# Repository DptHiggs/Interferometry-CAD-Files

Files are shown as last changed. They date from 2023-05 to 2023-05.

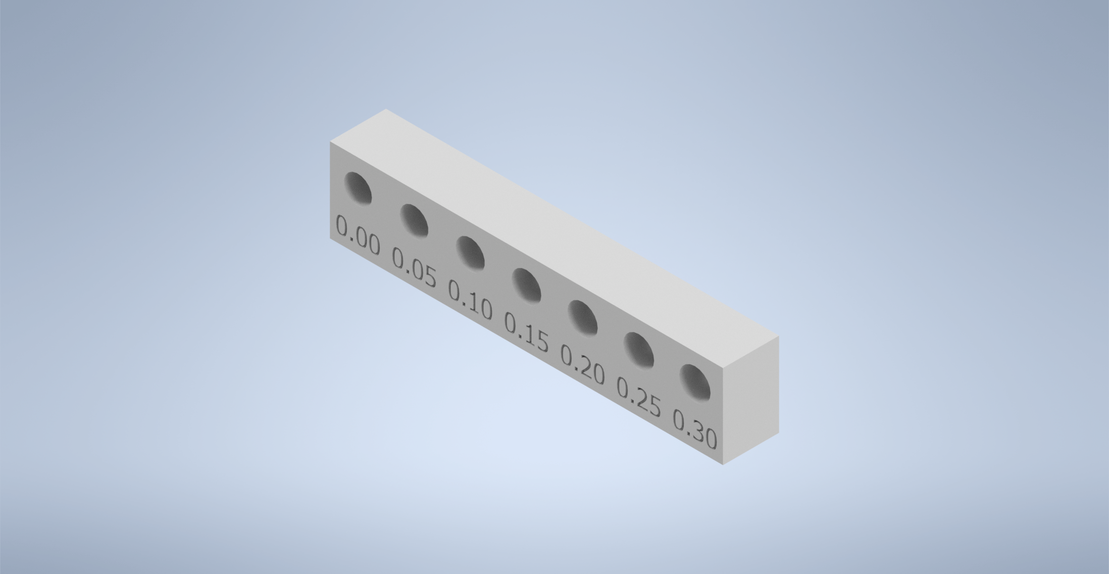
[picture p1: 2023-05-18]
RENDERS/FIT TEST.png

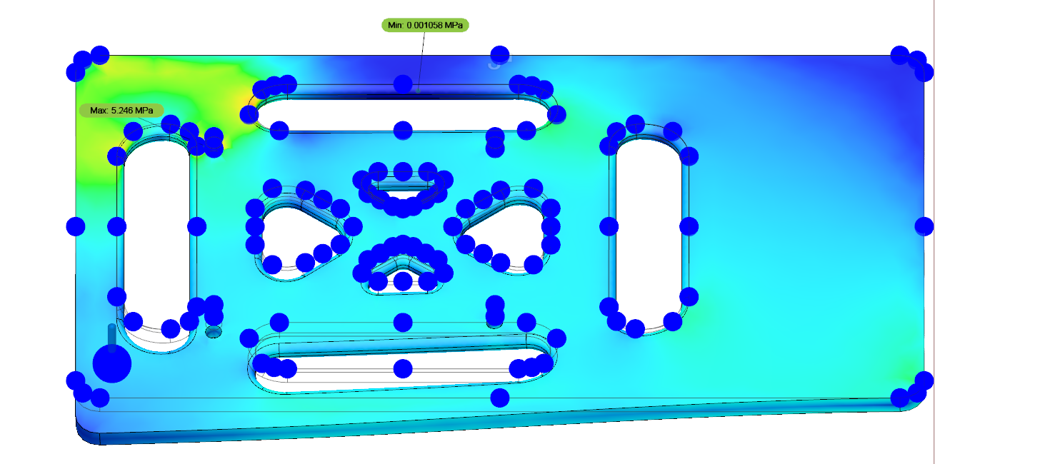
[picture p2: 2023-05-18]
SIMULATIONS/FEA/COMPONENT SHELF/COMPONENT SHELF 2/Screenshot 2023-05-17 142134.png

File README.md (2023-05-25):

# Interferometry-CAD-Files
Repository containing all CAD files and simulation reports for GDBP Lightning Interferometry enclosure design

All CAD files are stored in CAD folder <br>
LI designation denotes parts designed for this project <br>
LIA designation denotes assemblies designed for this project.

SIMULATIONS contains all simulation results and reports

RENDERS contains images of design

Links to other CAD files used <br>
https://grabcad.com/library/arduino-uno-r3-1 <br>
https://grabcad.com/library/raspberry-pi-4-model-b-1 <br>
https://uk.farnell.com/pulse-electronics/w9011m/cable-assy-u-fl-r-a-plug-sma-jack/dp/3861118 <br>
https://uk.rs-online.com/web/p/ethernet-couplers/1116746 <br>
https://uk.rs-online.com/web/p/usb-cables/1116748 <br>
https://uk.rs-online.com/web/p/fan-filters/7134396 <br>
https://www.accu.co.uk/threaded-hexagonal-spacers/464774-HHTPS-M3-5-5-8-SS?google_shopping=1&c=5 <br>
https://www.te.com/usa-en/product-1-1609112-4.html <br>
https://grabcad.com/library/arduino-due-1 <br>

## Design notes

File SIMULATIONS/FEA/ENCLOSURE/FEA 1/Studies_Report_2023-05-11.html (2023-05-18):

Image Width (pixels):

# Study Report

Analyzed File | LIA0003-CASE ASSY v2
Version | Autodesk Fusion 360 (2.0.16009)
Creation Date | 2023-05-11, 11:05:16
Author | rudy

#### Report Properties

Title | Studies
Author | rudy

## Simulation Model 1:1

### Study 1 - Static Stress

##### Study Properties

Study Type | Static Stress
Last Modification Date | 2023-05-11, 10:39:01

#### Settings

##### General

Contact Tolerance | 0.1 mm
Remove Rigid Body Modes | No

##### Damping

##### Mesh

Average Element Size (% of model size)
Solids | 10
Scale Mesh Size Per Part | No
Average Element Size (absolute value) | -
Element Order | Parabolic
Create Curved Mesh Elements | Yes
Max. Turn Angle on Curves (Deg.) | 60
Max. Adjacent Mesh Size Ratio | 1.5
Max. Aspect Ratio | 10
Minimum Element Size (% of average size) | 20

##### Adaptive Mesh Refinement

Number of Refinement Steps | 0
Results Convergence Tolerance (%) | 20
Portion of Elements to Refine (%) | 10
Results for Baseline Accuracy | Von Mises Stress

#### Materials

Component | Material | Safety Factor
LI0001-CASE BODY:1 | ABS Plastic | Yield Strength
LI0013-FOOT:1/Simplified Primitive:1 | Steel | Yield Strength
LI0013-FOOT:2/Simplified Primitive:1 | Steel | Yield Strength
LI0013-FOOT:3/Simplified Primitive:1 | Steel | Yield Strength
LI0013-FOOT:4/Simplified Primitive:1 | Steel | Yield Strength

##### Steel

Density | 7.85E-06 kg / mm^3
Young's Modulus | 210000 MPa
Poisson's Ratio | 0.3
Yield Strength | 207 MPa
Ultimate Tensile Strength | 345 MPa
Thermal Conductivity | 0.056 W / (mm C)
Thermal Expansion Coefficient | 1.2E-05 / C
Specific Heat | 480 J / (kg C)

##### ABS Plastic

Density | 1.06E-06 kg / mm^3
Young's Modulus | 2240 MPa
Poisson's Ratio | 0.38
Yield Strength | 20 MPa
Ultimate Tensile Strength | 29.6 MPa
Thermal Conductivity | 1.6E-04 W / (mm C)
Thermal Expansion Coefficient | 8.57E-05 / C
Specific Heat | 1500 J / (kg C)

#### Contacts

##### Bonded

Name

[S] Bonded56 [LI0001-CASE BODY:1||Simplified Primitive:1]

[S] Bonded57 [LI0001-CASE BODY:1||Simplified Primitive:1]

[S] Bonded58 [LI0001-CASE BODY:1||Simplified Primitive:1]

[S] Bonded59 [LI0001-CASE BODY:1||Simplified Primitive:1]

[S] Bonded60 [LI0001-CASE BODY:1||Simplified Primitive:1]

[S] Bonded61 [LI0001-CASE BODY:1||Simplified Primitive:1]

[S] Bonded62 [LI0001-CASE BODY:1||Simplified Primitive:1]

[S] Bonded63 [LI0001-CASE BODY:1||Simplified Primitive:1]

[S] Bonded64 [LI0001-CASE BODY:1||Simplified Primitive:1]

[S] Bonded65 [LI0001-CASE BODY:1||Simplified Primitive:1]

[S] Bonded66 [LI0001-CASE BODY:1||Simplified Primitive:1]

[S] Bonded67 [LI0001-CASE BODY:1||Simplified Primitive:1]

[S] Bonded68 [LI0001-CASE BODY:1||Simplified Primitive:1]

[S] Bonded69 [LI0001-CASE BODY:1||Simplified Primitive:1]

[S] Bonded70 [LI0001-CASE BODY:1||Simplified Primitive:1]

[S] Bonded71 [LI0001-CASE BODY:1||Simplified Primitive:1]

[S] Bonded72 [LI0001-CASE BODY:1||Simplified Primitive:1]

[S] Bonded73 [LI0001-CASE BODY:1||Simplified Primitive:1]

[S] Bonded74 [LI0001-CASE BODY:1||Simplified Primitive:1]

[S] Bonded75 [LI0001-CASE BODY:1||Simplified Primitive:1]

#### Mesh

Type | Nodes | Elements
Solids | 129011 | 68742

#### Load Case1

#### Constraints

##### Fixed2

Type | Fixed
Ux | Fixed
Uy | Fixed
Uz | Fixed

###### Selected Entities

For correct interpretation of this image use e.g. IE9, Chrome, Safari, Firefox

#### Loads

##### Force1

Type | Force
Magnitude | 1500 N
X Value | 9.228E-13 N
Y Value | -1500 N
Z Value | -2.76E-12 N
Force Per Entity | No

###### Selected Entities

For correct interpretation of this image use e.g. IE9, Chrome, Safari, Firefox

#### Results

##### Result Summary

Name | Minimum | Maximum
Safety Factor
Safety Factor (Per Body) | 0.7015 | 15
Stress
Von Mises | 0.008346 MPa | 28.51 MPa
1st Principal | -17.16 MPa | 21.78 MPa
3rd Principal | -36.74 MPa | 6.235 MPa
Normal XX | -34.11 MPa | 20.17 MPa
Normal YY | -26.72 MPa | 18.9 MPa
Normal ZZ | -20.49 MPa | 8.956 MPa
Shear XY | -7.571 MPa | 9.18 MPa
Shear YZ | -7.35 MPa | 5.464 MPa
Shear ZX | -4.326 MPa | 4.474 MPa
Displacement
Total | 0 mm | 7.125 mm
X | -1.063 mm | 1.691 mm
Y | -7.112 mm | 0.1182 mm
Z | -0.561 mm | 0.9409 mm
Reaction Force
Total | 0 N | 141.6 N
X | -61.23 N | 80.72 N
Y | -76.39 N | 126.7 N
Z | -45.75 N | 81.59 N
Strain
Equivalent | 1.142E-06 | 0.01682
1st Principal | -2.44E-06 | 0.01307
3rd Principal | -0.01757 | -5.284E-07
Normal XX | -0.009087 | 0.008904
Normal YY | -0.01172 | 0.006923
Normal ZZ | -0.003403 | 0.004603
Shear XY | -0.009329 | 0.01131
Shear YZ | -0.007275 | 0.006732
Shear ZX | -0.00533 | 0.005513
Contact Pressure
Total | 0 MPa | 32.68 MPa
X | -18.36 MPa | 32.01 MPa
Y | -5.269 MPa | 6.554 MPa
Z | -12.01 MPa | 8.218 MPa
Contact Force
Total | 0 N | 293.4 N
X | -211.6 N | 221.3 N
Y | -257 N | 131.9 N
Z | -64.65 N | 85.19 N

##### Safety Factor

###### Safety Factor (Per Body)

0 8

For correct interpretation of this image use e.g. IE9, Chrome, Safari, Firefox

##### Stress

###### Von Mises

[MPa] 0.01 28.51

For correct interpretation of this image use e.g. IE9, Chrome, Safari, Firefox

###### 1st Principal

[MPa] -17.16 21.78

For correct interpretation of this image use e.g. IE9, Chrome, Safari, Firefox

###### 3rd Principal

[MPa] -36.74 6.23

For correct interpretation of this image use e.g. IE9, Chrome, Safari, Firefox

##### Displacement

###### Total

[mm] 0 7.125

For correct interpretation of this image use e.g. IE9, Chrome, Safari, Firefox

Image Width (pixels):

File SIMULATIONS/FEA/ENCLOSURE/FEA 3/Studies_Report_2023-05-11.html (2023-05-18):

Image Width (pixels):

# Study Report

Analyzed File | LIA0003-CASE ASSY v2
Version | Autodesk Fusion 360 (2.0.16009)
Creation Date | 2023-05-11, 13:08:34
Author | Louis

#### Report Properties

Title | Studies
Author | Louis

## Simulation Model 1:1

### Study 1 - Static Stress

##### Study Properties

Study Type | Static Stress
Last Modification Date | 2023-05-11, 11:43:08

#### Settings

##### General

Contact Tolerance | 0.1 mm
Remove Rigid Body Modes | No

##### Damping

##### Mesh

Average Element Size (% of model size)
Solids | 10
Scale Mesh Size Per Part | No
Average Element Size (absolute value) | -
Element Order | Parabolic
Create Curved Mesh Elements | Yes
Max. Turn Angle on Curves (Deg.) | 60
Max. Adjacent Mesh Size Ratio | 1.5
Max. Aspect Ratio | 10
Minimum Element Size (% of average size) | 20

##### Adaptive Mesh Refinement

Number of Refinement Steps | 0
Results Convergence Tolerance (%) | 20
Portion of Elements to Refine (%) | 10
Results for Baseline Accuracy | Von Mises Stress

#### Materials

Component | Material | Safety Factor
LI0001-CASE BODY:1 | ABS Plastic | Yield Strength
LI0013-FOOT:1/Simplified Primitive:1 | Steel | Yield Strength
LI0013-FOOT:2/Simplified Primitive:1 | Steel | Yield Strength
LI0013-FOOT:3/Simplified Primitive:1 | Steel | Yield Strength
LI0013-FOOT:4/Simplified Primitive:1 | Steel | Yield Strength

##### Steel

Density | 7.85E-06 kg / mm^3
Young's Modulus | 210000 MPa
Poisson's Ratio | 0.3
Yield Strength | 207 MPa
Ultimate Tensile Strength | 345 MPa
Thermal Conductivity | 0.056 W / (mm C)
Thermal Expansion Coefficient | 1.2E-05 / C
Specific Heat | 480 J / (kg C)

##### ABS Plastic

Density | 1.06E-06 kg / mm^3
Young's Modulus | 2240 MPa
Poisson's Ratio | 0.38
Yield Strength | 20 MPa
Ultimate Tensile Strength | 29.6 MPa
Thermal Conductivity | 1.6E-04 W / (mm C)
Thermal Expansion Coefficient | 8.57E-05 / C
Specific Heat | 1500 J / (kg C)

#### Contacts

##### Bonded

Name

[S] Bonded1 [LI0001-CASE BODY:1||Simplified Primitive:1]

[S] Bonded2 [LI0001-CASE BODY:1||Simplified Primitive:1]

[S] Bonded3 [LI0001-CASE BODY:1||Simplified Primitive:1]

[S] Bonded4 [LI0001-CASE BODY:1||Simplified Primitive:1]

[S] Bonded5 [LI0001-CASE BODY:1||Simplified Primitive:1]

[S] Bonded6 [LI0001-CASE BODY:1||Simplified Primitive:1]

[S] Bonded7 [LI0001-CASE BODY:1||Simplified Primitive:1]

[S] Bonded8 [LI0001-CASE BODY:1||Simplified Primitive:1]

[S] Bonded9 [LI0001-CASE BODY:1||Simplified Primitive:1]

[S] Bonded10 [LI0001-CASE BODY:1||Simplified Primitive:1]

[S] Bonded11 [LI0001-CASE BODY:1||Simplified Primitive:1]

[S] Bonded12 [LI0001-CASE BODY:1||Simplified Primitive:1]

[S] Bonded13 [LI0001-CASE BODY:1||Simplified Primitive:1]

[S] Bonded14 [LI0001-CASE BODY:1||Simplified Primitive:1]

[S] Bonded15 [LI0001-CASE BODY:1||Simplified Primitive:1]

[S] Bonded16 [LI0001-CASE BODY:1||Simplified Primitive:1]

[S] Bonded17 [LI0001-CASE BODY:1||Simplified Primitive:1]

[S] Bonded18 [LI0001-CASE BODY:1||Simplified Primitive:1]

[S] Bonded19 [LI0001-CASE BODY:1||Simplified Primitive:1]

[S] Bonded20 [LI0001-CASE BODY:1||Simplified Primitive:1]

#### Mesh

Type | Nodes | Elements
Solids | 119018 | 62046

#### Load Case1

#### Constraints

##### Fixed1

Type | Fixed
Ux | Fixed
Uy | Fixed
Uz | Fixed

###### Selected Entities

For correct interpretation of this image use e.g. IE9, Chrome, Safari, Firefox

#### Loads

##### Force1

Type | Force
Magnitude | 1500 N
X Value | 9.228E-13 N
Y Value | -1500 N
Z Value | -2.843E-12 N
Force Per Entity | No

###### Selected Entities

For correct interpretation of this image use e.g. IE9, Chrome, Safari, Firefox

#### Results

##### Result Summary

Name | Minimum | Maximum
Safety Factor
Safety Factor (Per Body) | 0.8103 | 15
Stress
Von Mises | 0.006634 MPa | 24.68 MPa
1st Principal | -19.14 MPa | 22.07 MPa
3rd Principal | -46.16 MPa | 3.785 MPa
Normal XX | -41.34 MPa | 20.94 MPa
Normal YY | -23.94 MPa | 18.61 MPa
Normal ZZ | -24.81 MPa | 9.93 MPa
Shear XY | -10.23 MPa | 6.051 MPa
Shear YZ | -9.929 MPa | 5.776 MPa
Shear ZX | -4.501 MPa | 4.617 MPa
Displacement
Total | 0 mm | 7.429 mm
X | -1.123 mm | 1.785 mm
Y | -7.415 mm | 0.1243 mm
Z | -0.5888 mm | 0.9316 mm
Reaction Force
Total | 0 N | 157.1 N
X | -63.01 N | 92.12 N
Y | -77.46 N | 145.2 N
Z | -45.59 N | 89.51 N
Strain
Equivalent | 1.136E-06 | 0.01691
1st Principal | -5.15E-07 | 0.01256
3rd Principal | -0.01866 | -3.67E-07
Normal XX | -0.01018 | 0.007885
Normal YY | -0.00913 | 0.006728
Normal ZZ | -0.003009 | 0.003217
Shear XY | -0.01261 | 0.007455
Shear YZ | -0.01223 | 0.007117
Shear ZX | -0.005545 | 0.005689
Contact Pressure
Total | 0 MPa | 39.29 MPa
X | -19.21 MPa | 38.45 MPa
Y | -6.712 MPa | 8.046 MPa
Z | -12.58 MPa | 8.513 MPa
Contact Force
Total | 0 N | 338.8 N
X | -235.9 N | 170.9 N
Y | -250.2 N | 145.1 N
Z | -54.93 N | 84.74 N

##### Safety Factor

###### Safety Factor (Per Body)

0 8

For correct interpretation of this image use e.g. IE9, Chrome, Safari, Firefox

##### Stress

###### Von Mises

[MPa] 0.01 24.68

For correct interpretation of this image use e.g. IE9, Chrome, Safari, Firefox

###### 1st Principal

[MPa] -19.14 22.07

For correct interpretation of this image use e.g. IE9, Chrome, Safari, Firefox

###### 3rd Principal

[MPa] -46.16 3.78

For correct interpretation of this image use e.g. IE9, Chrome, Safari, Firefox

##### Displacement

###### Total

[mm] 0 7.429

For correct interpretation of this image use e.g. IE9, Chrome, Safari, Firefox

Image Width (pixels):

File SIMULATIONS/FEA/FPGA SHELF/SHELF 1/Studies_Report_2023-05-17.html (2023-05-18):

Image Width (pixels):

# Study Report

Analyzed File | LI0009-XILINX SHELF v4
Version | Autodesk Fusion 360 (2.0.16009)
Creation Date | 2023-05-17, 13:03:51
Author | Louis

#### Report Properties

Title | Studies
Author | rudy

## Simulation Model 1:1

### Study 1 - Static Stress

##### Study Properties

Study Type | Static Stress
Last Modification Date | 2023-05-15, 17:20:15

#### Settings

##### General

Contact Tolerance | 0.1 mm
Remove Rigid Body Modes | No

##### Damping

##### Mesh

Average Element Size (% of model size)
Solids | 10
Scale Mesh Size Per Part | No
Average Element Size (absolute value) | -
Element Order | Parabolic
Create Curved Mesh Elements | Yes
Max. Turn Angle on Curves (Deg.) | 60
Max. Adjacent Mesh Size Ratio | 1.5
Max. Aspect Ratio | 10
Minimum Element Size (% of average size) | 20

##### Adaptive Mesh Refinement

Number of Refinement Steps | 0
Results Convergence Tolerance (%) | 20
Portion of Elements to Refine (%) | 10
Results for Baseline Accuracy | Von Mises Stress

#### Materials

Component | Material | Safety Factor
Body1 | ABS Plastic | Yield Strength

##### ABS Plastic

Density | 1.06E-06 kg / mm^3
Young's Modulus | 2240 MPa
Poisson's Ratio | 0.38
Yield Strength | 20 MPa
Ultimate Tensile Strength | 29.6 MPa
Thermal Conductivity | 1.6E-04 W / (mm C)
Thermal Expansion Coefficient | 8.57E-05 / C
Specific Heat | 1500 J / (kg C)

#### Contacts

#### Mesh

Type | Nodes | Elements
Solids | 6281 | 2923

#### Load Case1

#### Constraints

##### Fixed1

Type | Fixed
Ux | Fixed
Uy | Fixed
Uz | Fixed

###### Selected Entities

For correct interpretation of this image use e.g. IE9, Chrome, Safari, Firefox

##### Fixed2

Type | Fixed
Ux | Free
Uy | Fixed
Uz | Fixed

###### Selected Entities

For correct interpretation of this image use e.g. IE9, Chrome, Safari, Firefox

#### Loads

##### Remote Force1

Type | Remote Force
Magnitude | 10 N
X Value | 0 N
Y Value | 0 N
Z Value | -10 N
Position X | 100 mm
Position Y | -110 mm
Position Z | 3 mm

###### Selected Entities

For correct interpretation of this image use e.g. IE9, Chrome, Safari, Firefox

#### Results

##### Result Summary

Name | Minimum | Maximum
Safety Factor
Safety Factor (Per Body) | 0.6756 | 15
Stress
Von Mises | 5.433E-05 MPa | 29.6 MPa
1st Principal | -17.8 MPa | 31.4 MPa
3rd Principal | -31.93 MPa | 9.378 MPa
Normal XX | -17.86 MPa | 12.88 MPa
Normal YY | -30.31 MPa | 30.03 MPa
Normal ZZ | -17.86 MPa | 9.38 MPa
Shear XY | -9.359 MPa | 8.639 MPa
Shear YZ | -5.382 MPa | 4.238 MPa
Shear ZX | -4.07 MPa | 2.616 MPa
Displacement
Total | 0 mm | 73.02 mm
X | -0.5765 mm | 0.5764 mm
Y | -0.6173 mm | 0.6174 mm
Z | -73.02 mm | 0.009251 mm
Reaction Force
Total | 0 N | 339.4 N
X | -16.78 N | 25.56 N
Y | -118.2 N | 95.38 N
Z | -338.9 N | 178.9 N
Strain
Equivalent | 2.887E-08 | 0.01756
1st Principal | 2.865E-08 | 0.01587
3rd Principal | -0.01849 | -2.058E-08
Normal XX | -0.004072 | 0.003951
Normal YY | -0.01285 | 0.01283
Normal ZZ | -0.005418 | 0.005397
Shear XY | -0.01153 | 0.01064
Shear YZ | -0.006631 | 0.005222
Shear ZX | -0.005014 | 0.003223
Contact Force
Total | 0 N | 0 N
X | 0 N | 0 N
Y | 0 N | 0 N
Z | 0 N | 0 N

##### Safety Factor

###### Safety Factor (Per Body)

0 8

For correct interpretation of this image use e.g. IE9, Chrome, Safari, Firefox

##### Stress

###### Von Mises

[MPa] 0 29.6

For correct interpretation of this image use e.g. IE9, Chrome, Safari, Firefox

###### 1st Principal

[MPa] -17.8 31.4

For correct interpretation of this image use e.g. IE9, Chrome, Safari, Firefox

###### 3rd Principal

[MPa] -31.93 9.38

For correct interpretation of this image use e.g. IE9, Chrome, Safari, Firefox

##### Displacement

###### Total

[mm] 0 73.02

For correct interpretation of this image use e.g. IE9, Chrome, Safari, Firefox

Image Width (pixels):

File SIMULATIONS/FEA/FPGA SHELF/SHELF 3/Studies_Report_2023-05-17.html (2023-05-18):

Image Width (pixels):

# Study Report

Analyzed File | LI0009-XILINX SHELF v2
Version | Autodesk Fusion 360 (2.0.16009)
Creation Date | 2023-05-17, 13:34:41
Author | Louis

#### Report Properties

Title | Studies
Author | Louis

## Simulation Model 1:1

### Study 1 - Static Stress

##### Study Properties

Study Type | Static Stress
Last Modification Date | 2023-05-17, 13:15:53

#### Settings

##### General

Contact Tolerance | 0.1 mm
Remove Rigid Body Modes | No

##### Damping

##### Mesh

Average Element Size (% of model size)
Solids | 10
Scale Mesh Size Per Part | No
Average Element Size (absolute value) | -
Element Order | Parabolic
Create Curved Mesh Elements | Yes
Max. Turn Angle on Curves (Deg.) | 60
Max. Adjacent Mesh Size Ratio | 1.5
Max. Aspect Ratio | 10
Minimum Element Size (% of average size) | 20

##### Adaptive Mesh Refinement

Number of Refinement Steps | 0
Results Convergence Tolerance (%) | 20
Portion of Elements to Refine (%) | 10
Results for Baseline Accuracy | Von Mises Stress

#### Materials

Component | Material | Safety Factor
Body1 | ABS Plastic | Yield Strength

##### ABS Plastic

Density | 1.06E-06 kg / mm^3
Young's Modulus | 2240 MPa
Poisson's Ratio | 0.38
Yield Strength | 20 MPa
Ultimate Tensile Strength | 29.6 MPa
Thermal Conductivity | 1.6E-04 W / (mm C)
Thermal Expansion Coefficient | 8.57E-05 / C
Specific Heat | 1500 J / (kg C)

#### Contacts

#### Mesh

Type | Nodes | Elements
Solids | 44848 | 23530

#### Load Case1

#### Constraints

##### Fixed1

Type | Fixed
Ux | Fixed
Uy | Free
Uz | Fixed

###### Selected Entities

For correct interpretation of this image use e.g. IE9, Chrome, Safari, Firefox

##### Fixed2

Type | Fixed
Ux | Fixed
Uy | Fixed
Uz | Fixed

###### Selected Entities

For correct interpretation of this image use e.g. IE9, Chrome, Safari, Firefox

#### Loads

##### Remote Force1

Type | Remote Force
Magnitude | 10 N
X Value | 0 N
Y Value | 0 N
Z Value | -10 N
Position X | 100 mm
Position Y | -110 mm
Position Z | 5 mm

###### Selected Entities

For correct interpretation of this image use e.g. IE9, Chrome, Safari, Firefox

#### Results

##### Result Summary

Name | Minimum | Maximum
Safety Factor
Safety Factor (Per Body) | 2.71 | 15
Stress
Von Mises | 1.454E-05 MPa | 7.38 MPa
1st Principal | -3.842 MPa | 8.083 MPa
3rd Principal | -8.025 MPa | 4.035 MPa
Normal XX | -7.397 MPa | 8.021 MPa
Normal YY | -7.444 MPa | 6.717 MPa
Normal ZZ | -3.997 MPa | 4.117 MPa
Shear XY | -2.421 MPa | 2.6 MPa
Shear YZ | -1.418 MPa | 1.478 MPa
Shear ZX | -1.421 MPa | 1.434 MPa
Displacement
Total | 0 mm | 11.95 mm
X | -0.1846 mm | 0.1846 mm
Y | -0.1706 mm | 0.1706 mm
Z | -11.95 mm | 0.03166 mm
Reaction Force
Total | 0 N | 66.74 N
X | -57.75 N | 49.06 N
Y | -56.55 N | 59.02 N
Z | -63.99 N | 35.84 N
Strain
Equivalent | 8.823E-09 | 0.004133
1st Principal | 5.861E-09 | 0.004283
3rd Principal | -0.003969 | -7.119E-09
Normal XX | -0.003053 | 0.003328
Normal YY | -0.002868 | 0.002921
Normal ZZ | -0.001282 | 0.001202
Shear XY | -0.002983 | 0.003203
Shear YZ | -0.001747 | 0.001821
Shear ZX | -0.001751 | 0.001767
Contact Force
Total | 0 N | 0 N
X | 0 N | 0 N
Y | 0 N | 0 N
Z | 0 N | 0 N

##### Safety Factor

###### Safety Factor (Per Body)

0 8

For correct interpretation of this image use e.g. IE9, Chrome, Safari, Firefox

##### Stress

###### Von Mises

[MPa] 0 7.38

For correct interpretation of this image use e.g. IE9, Chrome, Safari, Firefox

###### 1st Principal

[MPa] -3.842 8.083

For correct interpretation of this image use e.g. IE9, Chrome, Safari, Firefox

###### 3rd Principal

[MPa] -8.025 4.035

For correct interpretation of this image use e.g. IE9, Chrome, Safari, Firefox

##### Displacement

###### Total

[mm] 0 11.95

For correct interpretation of this image use e.g. IE9, Chrome, Safari, Firefox

Image Width (pixels):

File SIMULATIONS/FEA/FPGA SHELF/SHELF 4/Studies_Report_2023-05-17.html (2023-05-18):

Image Width (pixels):

# Study Report

Analyzed File | LI0009-XILINX SHELF v2
Version | Autodesk Fusion 360 (2.0.16009)
Creation Date | 2023-05-17, 14:14:16
Author | Louis

#### Report Properties

Title | Studies
Author | Louis

## Simulation Model 1:1

### Study 1 - Static Stress

##### Study Properties

Study Type | Static Stress
Last Modification Date | 2023-05-17, 14:13:22

#### Settings

##### General

Contact Tolerance | 0.1 mm
Remove Rigid Body Modes | No

##### Damping

##### Mesh

Average Element Size (% of model size)
Solids | 10
Scale Mesh Size Per Part | No
Average Element Size (absolute value) | -
Element Order | Parabolic
Create Curved Mesh Elements | Yes
Max. Turn Angle on Curves (Deg.) | 60
Max. Adjacent Mesh Size Ratio | 1.5
Max. Aspect Ratio | 10
Minimum Element Size (% of average size) | 20

##### Adaptive Mesh Refinement

Number of Refinement Steps | 0
Results Convergence Tolerance (%) | 20
Portion of Elements to Refine (%) | 10
Results for Baseline Accuracy | Von Mises Stress

#### Materials

Component | Material | Safety Factor
Body1 | PET Plastic | Yield Strength

##### PET Plastic

Density | 1.541E-06 kg / mm^3
Young's Modulus | 2758 MPa
Poisson's Ratio | 0.417
Yield Strength | 54.4 MPa
Ultimate Tensile Strength | 55.1 MPa
Thermal Conductivity | 3E-04 W / (mm C)
Thermal Expansion Coefficient | 7.02E-07 / C
Specific Heat | 2287 J / (kg C)

#### Contacts

#### Mesh

Type | Nodes | Elements
Solids | 44183 | 23268

#### Load Case1

#####  Solve result of this load case is out of date.

#### Constraints

##### Fixed1

Type | Fixed
Ux | Free
Uy | Fixed
Uz | Fixed

###### Selected Entities

For correct interpretation of this image use e.g. IE9, Chrome, Safari, Firefox

##### Fixed2

Type | Fixed
Ux | Fixed
Uy | Free
Uz | Fixed

###### Selected Entities

For correct interpretation of this image use e.g. IE9, Chrome, Safari, Firefox

#### Loads

##### Remote Force1

Type | Remote Force
Magnitude | 10 N
X Value | 0 N
Y Value | 0 N
Z Value | -10 N
Position X | 100 mm
Position Y | -110 mm
Position Z | 5 mm

###### Selected Entities

For correct interpretation of this image use e.g. IE9, Chrome, Safari, Firefox

#### Results

##### Result Summary

Name | Minimum | Maximum
Safety Factor
Safety Factor (Per Body) | 3.883 | 15
Stress
Von Mises | 2.457E-04 MPa | 5.15 MPa
1st Principal | -3.263 MPa | 5.456 MPa
3rd Principal | -5.702 MPa | 2.846 MPa
Normal XX | -5.634 MPa | 5.408 MPa
Normal YY | -5.013 MPa | 5.049 MPa
Normal ZZ | -3.383 MPa | 3.014 MPa
Shear XY | -1.639 MPa | 1.515 MPa
Shear YZ | -0.985 MPa | 1.051 MPa
Shear ZX | -0.9656 MPa | 0.9978 MPa
Displacement
Total | 6.992E-09 mm | 7.258 mm
X | -0.112 mm | 0.112 mm
Y | -0.1038 mm | 0.1037 mm
Z | -7.257 mm | 0.03458 mm
Reaction Force
Total | 0 N | 55.52 N
X | -43.78 N | 36.81 N
Y | -45.01 N | 38.45 N
Z | -55.52 N | 36.41 N
Strain
Equivalent | 1.166E-07 | 0.002675
1st Principal | 5.886E-08 | 0.002776
3rd Principal | -0.002664 | -6.026E-08
Normal XX | -0.002236 | 0.002294
Normal YY | -0.00212 | 0.002102
Normal ZZ | -9.45E-04 | 9.699E-04
Shear XY | -0.002019 | 0.001867
Shear YZ | -0.001214 | 0.001295
Shear ZX | -0.00119 | 0.001229
Contact Force
Total | 0 N | 0 N
X | 0 N | 0 N
Y | 0 N | 0 N
Z | 0 N | 0 N

##### Safety Factor

###### Safety Factor (Per Body)

0 8

For correct interpretation of this image use e.g. IE9, Chrome, Safari, Firefox

##### Stress

###### Von Mises

[MPa] 0 5.15

For correct interpretation of this image use e.g. IE9, Chrome, Safari, Firefox

###### 1st Principal

[MPa] -3.263 5.456

For correct interpretation of this image use e.g. IE9, Chrome, Safari, Firefox

###### 3rd Principal

[MPa] -5.702 2.846

For correct interpretation of this image use e.g. IE9, Chrome, Safari, Firefox

##### Displacement

###### Total

[mm] 0 7.258

For correct interpretation of this image use e.g. IE9, Chrome, Safari, Firefox

Image Width (pixels):

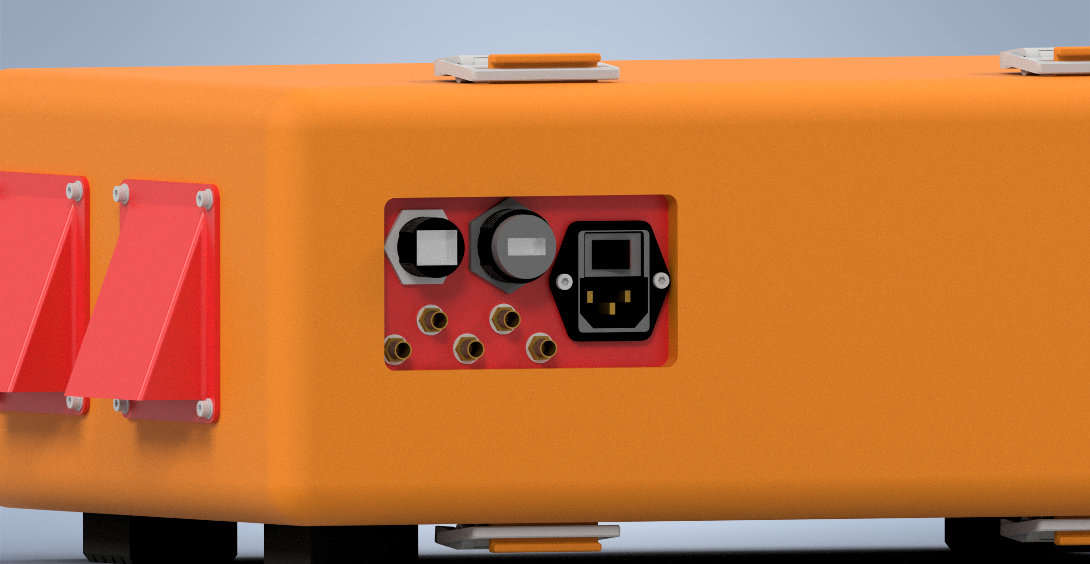
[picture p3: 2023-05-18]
RENDERS/LIA0003-CASE ASSY 3.png

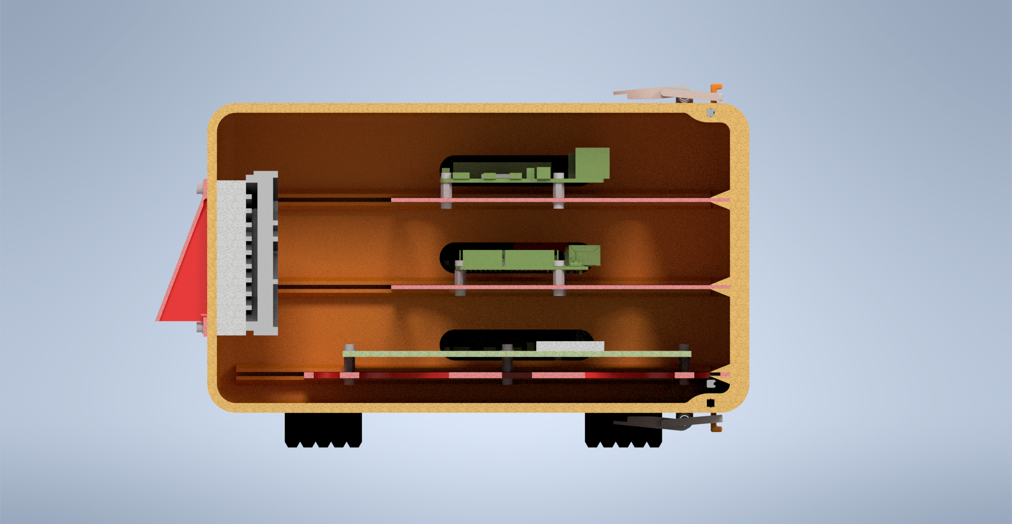
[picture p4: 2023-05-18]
RENDERS/LIA0003-CASE ASSY DRIVES.png

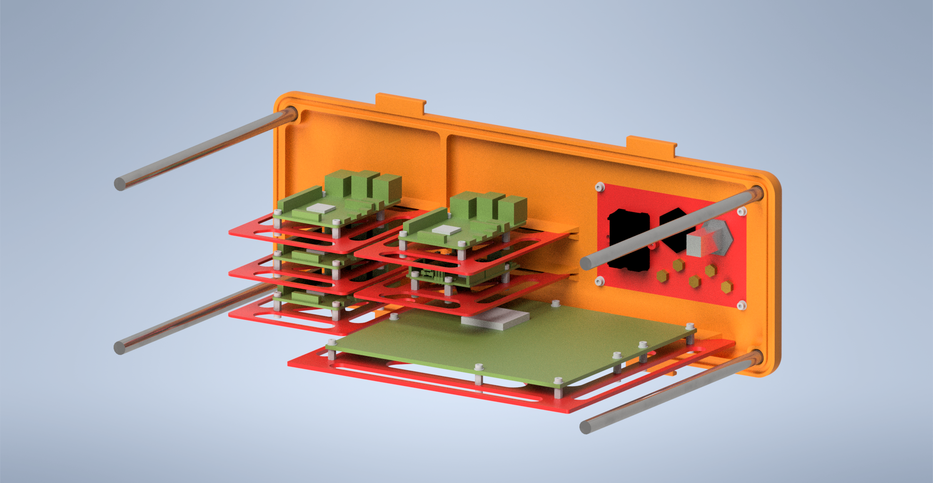
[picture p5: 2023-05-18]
RENDERS/LIA0002-LID ASSY.png

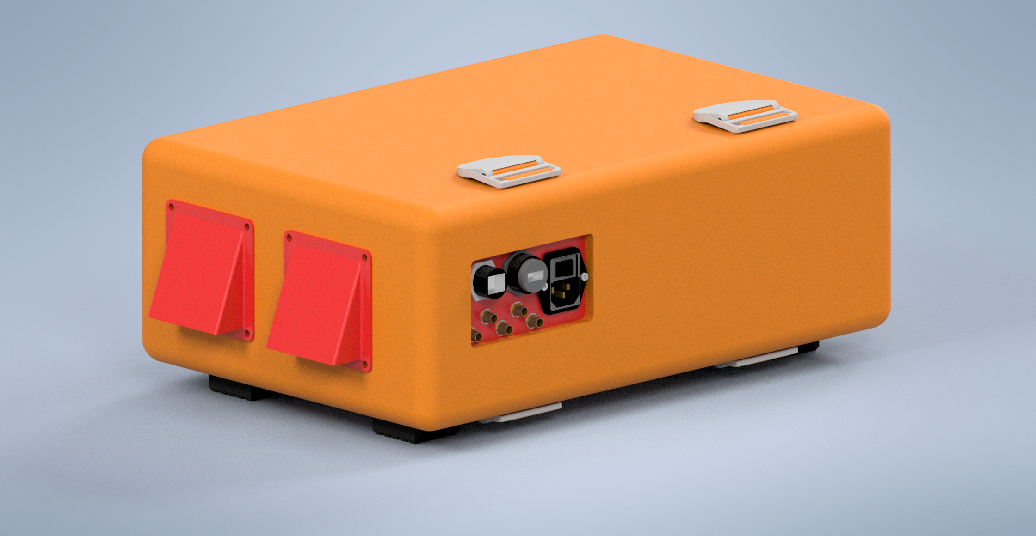
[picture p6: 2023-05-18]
RENDERS/LIA0003-CASE ASSY.png

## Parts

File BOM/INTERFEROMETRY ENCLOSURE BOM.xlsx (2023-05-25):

Item | Part Number | Thumbnail | BOM Structure | Unit QTY | QTY | Description | Weight (g) | Cost (£) | Sum (£)
1 | LI0001-CASE BODY |  | Normal | Each | 1 | Outer casing for enclosure | 1329 | £26.58 | £26.58
2 | LI0005-SEAL |  | Normal | Each | 1 | Seal for enclosure body | 19 | £0.38 | £0.38
3 | LI0006-CLASP |  | Normal | Each | 4 | clasp for lid latching mechanism | 4.37 | £0.09 | £0.35
4 | LI0007-LATCH |  | Normal | Each | 4 | Latch for lid latching mechanism | 2.34 | £0.05 | £0.19
5 | FAN SPACE MODEL |  | Normal | Each | 4 | Space model to represent an 80mm fan https://uk.rs-online.com/web/p/axial-fans/1919379 | * | £24.07 | £96.28
6 | LI0002-CASE LID |  | Normal | Each | 1 | Lid for enclosure | 310 | £6.20 | £6.20
7 | LI0004-ROD |  | Normal | Each | 4 | 10mm guide rods for installing lid to enclosure https://uk.rs-online.com/web/p/plastic-rods/0514512 | * | £3.51 | £14.04
8 | LI0011-IO SHIELD |  | Normal | Each | 1 | Shield to hold all I/O components | 17 | £0.34 | £0.34
9 | RS PRO USB 2.0 Cable, Female USB A to Male USB A USB Extension Cable, 200mm |  | Normal | Each | 1 | Space model for USB connector https://uk.rs-online.com/web/p/usb-cables/1116748 | * | £29.58 | £29.58
10 | W9011M COAXIAL CONNECTOR |  | Normal | Each | 5 | Space model for coaxial connector https://uk.farnell.com/pulse-electronics/w9011m/cable-assy-u-fl-r-a-plug-sma-jack/dp/3861118 | * | £3.08 | £15.40
11 | c-1-1609112-4-c-3d |  | Normal | Each | 1 | Space model for switch AC power input https://www.te.com/usa-en/product-1-1609112-4.html | * | £17.00 | £17.00
12 | LI0012-IO SHIELD SEAL |  | Normal | Each | 1 | Seal for I/O shield | 2 | £0.04 | £0.04
13 | M3 WASHER |  | Normal | Each | 58 | M3 washer https://www.accu.co.uk/flat-washers/72482-HPW-M3-A2 | * | £0.45 | £26.10
14 | M3 X 6 |  | Normal | Each | 56 | Cap head M3 bolt 6mm long https://www.accu.co.uk/cap-head-screws/3817-SSCF-M3-6-A2 | * | £0.51 | £28.56
15 | LI0009 XILINX SHELF |  | Normal | Each | 1 | Shelf for FPGA board | 111 | £2.22 | £2.22
16 | XILINX BOARD FOOTPRINT |  | Normal | Each | 1 | Space model for FPGA board footprint | * | £0.00 | £0.00
17 | HHTPS-M3-5-8-S-Z |  | Normal | Each | 25 | M3 x 8mm x 5.5mm Threaded Hexagon Spacers https://www.accu.co.uk/threaded-hexagonal-spacers/464774-HHTPS-M3-5-5-8-SS?google_shopping=1&c=5 | * | £2.77 | £69.25
18 | LI0003-COMPONENT SHELF |  | Normal | Each | 4 | Shelf for mounting components | 39 | £0.78 | £3.12
19 | rcp-080-t_3D1 |  | Normal | Each | 4 | Space model for fan filter https://uk.rs-online.com/web/p/fan-filters/7134396 | * | £3.50 | £14.00
20 | LI0010-FAN SHROUD |  | Normal | Each | 5 | Exterior rain cover for fan vents | 31 | £0.62 | £3.10
21 | LI0013-FOOT |  | Normal | Each | 4 | supporting foot for enclosure | 13 | £0.26 | £1.04
22 | LI0017-LATCH BARREL |  | Normal | Each | 4 | Glue in place barrel for latch mechanism | 4 | £0.08 | £0.32
23 | LI0008-LATCH PIN |  | Normal | Each | 4 | Pin for securing latch mechanism | 1 | £0.02 | £0.08
24 | M3 X 25 |  | Normal | Each | 16 | Cap head M3 bolt 25mm long https://www.accu.co.uk/cap-head-screws/2804-SSC-M3-25-A2 | * | £0.55 | £8.80
25 | M3 X 10 |  | Normal | Each | 4 | Cap head M3 bolt 10mm long https://www.accu.co.uk/cap-head-screws/3819-SSCF-M3-10-A2 | * | £0.48 | £1.92
26 | RJFTV21 X Amphenol Connector |  | Normal | Each | 1 | Amphenol RJFTV Female RJ45 Connector Cat5e, RJFTV https://uk.rs-online.com/web/p/ethernet-connectors/6950289?matchtype=p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 | * | 57.29 | £57.29
27 | LI0018-NETWORKING SHELF |  | Normal | Each | 1 | Shelf for networking board | 39 | 0.78 | £0.78
28 | ACCU HHTPS-M2.5-5-8-S-Z |  | Normal | Each | 8 | M2.5 x 8mm x 5.5mm Threaded Hexagon Spacers https://www.accu.co.uk/threaded-hexagonal-spacers/464672-HHTPS-M2-5-5-8-BR-NI | * | £1.24 | £9.92
29 | M2.5 X 6 |  | Normal | Each | 16 | Cap head M2.5 bolt 6mm long https://www.accu.co.uk/cap-head-screws/3804-SSCF-M2-5-6-A2 | * | £0.52 | £8.32
30 | M2.5 WASHER |  | Normal | Each | 8 | M2.5 flat washer https://www.accu.co.uk/flat-washers/72477-HPW-M2-5-A2 | * | 0.45 | £3.60
 |  |  |  |  |  |  |  |  | £444.80 | £44.74

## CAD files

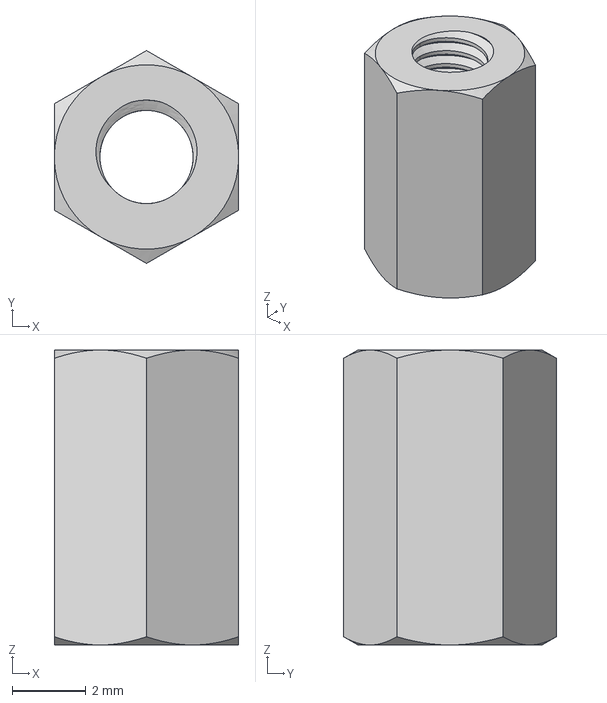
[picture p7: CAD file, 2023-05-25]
CAD/OTHER PARTS/HHTPS-M3-5-8-S-Z v1.step
5.00 x 5.77 x 8.00 mm

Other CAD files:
CAD/ENCLOSURE ASSEMBLIES/LIA0001-SHELF.iam
CAD/ENCLOSURE ASSEMBLIES/LIA0003-CASE ASSY.iam
CAD/ENCLOSURE ASSEMBLIES/LIA0004-XILINX SHELF ASSY.iam
CAD/ENCLOSURE ASSEMBLIES/LIA0005-IO SHIELD ASSY.iam
CAD/ENCLOSURE ASSEMBLIES/LIA0006-ARDUINO SHELF.iam
CAD/ENCLOSURE ASSEMBLIES/LIA0007-NETWORKING SHELF.iam
CAD/ENCLOSURE PARTS/LI0001-CASE BODY.ipt
CAD/ENCLOSURE PARTS/LI0002-CASE LID.ipt
CAD/ENCLOSURE PARTS/LI0003-COMPONENT SHELF.ipt
CAD/ENCLOSURE PARTS/LI0004-ROD.ipt
CAD/ENCLOSURE PARTS/LI0005-SEAL.ipt
CAD/ENCLOSURE PARTS/LI0006-CLASP.ipt
CAD/ENCLOSURE PARTS/LI0007-LATCH.ipt
CAD/ENCLOSURE PARTS/LI0008-LATCH PIN.ipt
CAD/ENCLOSURE PARTS/LI0009-XILINX SHELF.ipt
CAD/ENCLOSURE PARTS/LI0010-FAN SHROUD.ipt
CAD/ENCLOSURE PARTS/LI0011-IO SHIELD.ipt
CAD/ENCLOSURE PARTS/LI0012-IO SHIELD SEAL.ipt
CAD/ENCLOSURE PARTS/LI0013-FOOT.ipt
CAD/ENCLOSURE PARTS/LI0014-ARDUINO SHELF.ipt
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
